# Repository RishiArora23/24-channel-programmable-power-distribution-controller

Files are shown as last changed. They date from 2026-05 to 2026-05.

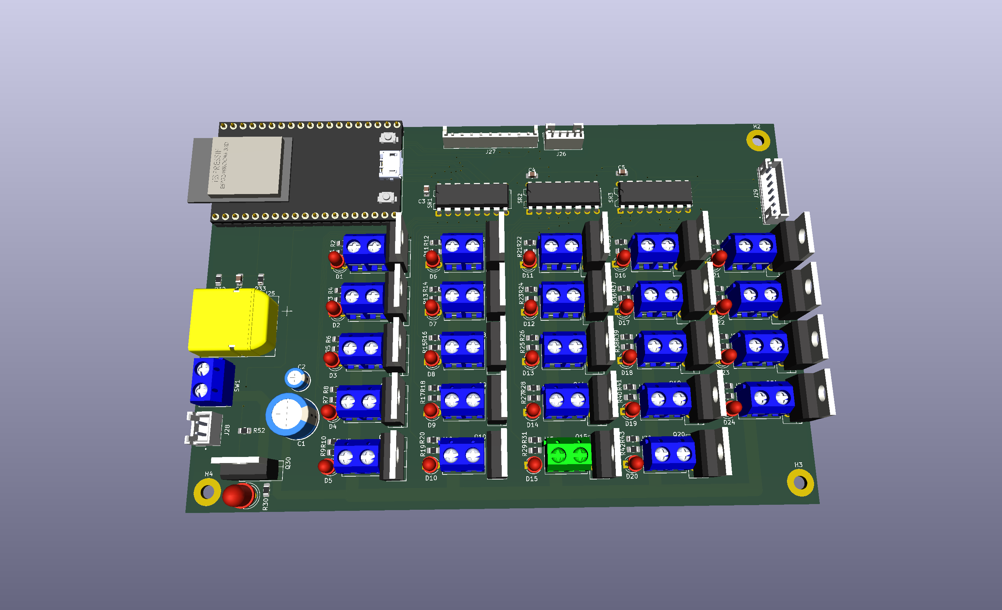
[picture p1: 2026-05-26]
images/pcb-layout_3d.png

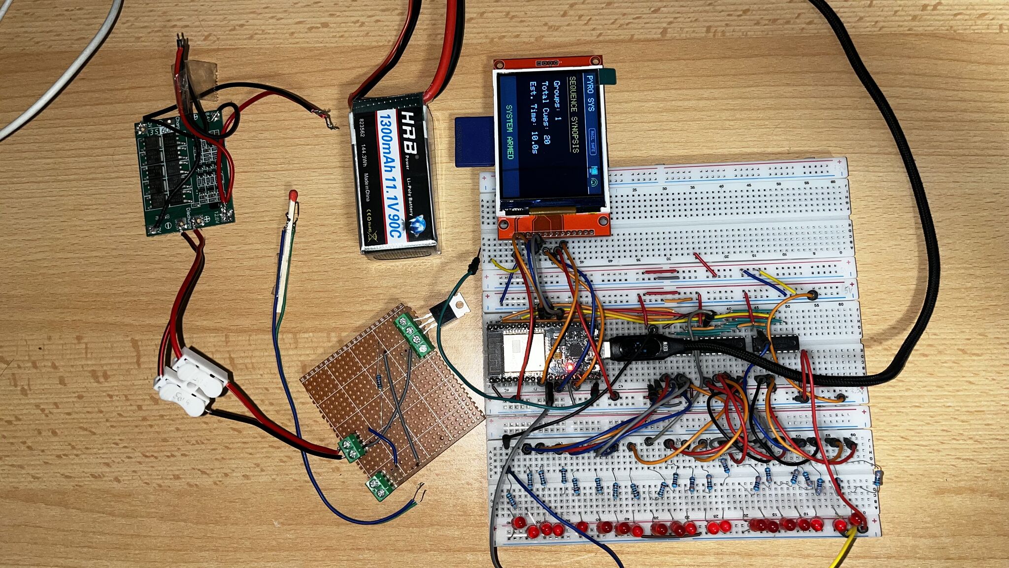
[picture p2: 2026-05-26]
images/prototype-photo.jpg

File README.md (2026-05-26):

# 24-Channel Programmable Power Distribution Controller

An ESP32-based programmable firing controller for sequenced 24-channel power distribution. The system combines embedded firmware, a KiCad-designed PCB, and a PyQt5 desktop application to enable fully programmable, remotely triggered output sequences — with hardware safety interlocks and a real-time TFT display.

> ⚠️ **Safety Notice:** This system switches high-current loads via power MOSFETs. Always follow applicable electrical safety guidelines. Never connect live loads during programming or testing.

---

## How It Works

Each of the 24 output channels is driven by an **IRLZ44N N-Channel MOSFET** (55 V, 47 A) switched via a **3× cascaded shift register** chain. The ESP32 clocks channel states into the shift registers over SPI, allowing all 24 outputs to be independently toggled in any order or pattern. A 12 V rail MOSFET acts as a master power switch, controlled by software arm/disarm commands.

The desktop app (`main.py`) communicates with the ESP32 over **Wi-Fi (TCP port 8080)** or via **UDP auto-discovery** (port 4210). Sequences are authored graphically in the app, serialized to JSON, and uploaded to the ESP32 at runtime — no re-flashing required.

---

## System Architecture

```
[ PyQt5 Desktop App ] ──WiFi TCP/UDP──► [ ESP32 Firmware ]
         │                                      │
   Sequence Editor                    Shift Registers (×3)
   Group/Pattern UI                         │
   Arm / Fire Controls              [ 24× IRLZ44N MOSFETs ]
                                            │
                                    [ Output Terminals J1–J24 ]
```

---

## Hardware

**Key components (from KiCad schematic):**
- **MCU:** ESP32 (Arduino framework)
- **Output switches:** 24× IRLZ44N MOSFETs in TO-220 package
- **Channel indicators:** 24× LEDs with 220 Ω series resistors
- **Gate drive:** 10 kΩ pull-down resistors per MOSFET gate
- **Shift registers:** 3× 8-bit shift registers (SRCLK → pin 23, RCLK → pin 21, SER → pin 22, OE → pin 19, SRCLR → pin 18)
- **Rail safety:** MOSFET switch on pin 27, analog voltage sense on pin 34
- **Display:** ILI9341 TFT (HSPI: MOSI 13, CLK 14, MISO 12, CS 5, DC 4, RST 17)
- **Output connectors:** 24× 2-pin 5.08 mm terminal blocks (J1–J24)

**Project files:**

| File | Description |
|---|---|
| `*.kicad_sch` | Schematic (channel sub-sheets × 24 + top sheet) |
| `*.kicad_pcb` | PCB layout |
| `*.kicad_pro` | KiCad project file |

---

## Firmware (`*.ino`)

Written in Arduino C++ for ESP32. Key responsibilities:

- **WiFiManager** captive portal for first-time Wi-Fi setup (AP: `Pyro-Setup-AP`)
- TCP server on port **8080** for desktop app communication
- UDP listener on port **4210** for auto-discovery
- Shift register management: channels fire for **1000 ms** then auto-clear
- JSON sequence parser (`ArduinoJson`) supporting up to **20 groups × 24 steps**
- Built-in web UI accessible from any browser on the network (manual fire, arm/disarm, sequence status)
- Real-time TFT UI with state machine: `IDLE → ARMED → COUNTDOWN → EXECUTING → FINISHED`

**ESP32 Pin Summary:**

| Function | Pin |
|---|-----|
| Rail MOSFET (arm) | 27 |
| Rail voltage sense | 34 |
| Shift reg SRCLK | 23 |
| Shift reg RCLK | 21 |
| Shift reg SER | 22 |
| Shift reg OE | 19 |
| Shift reg SRCLR | 18 |
| TFT MOSI/CLK/MISO/CS/DC/RST | 13/14/12/5/4/17 |

---

## Desktop App (`main.py`)

PyQt5 GUI application. Requires Python 3 and the following packages:

```bash
pip install PyQt5 pyserial
```

**Features:**
- Initialize a sequence with N cues (up to 24)
- Build named **groups** with patterns: Right Wave, Left Wave, Alternate, Center Burst, Inwards, All Fire
- Set inter-step gap (ms) per group
- Upload sequence as JSON to ESP32 over Wi-Fi
- Arm/disarm rail, monitor live rail voltage safety status
- Countdown display and per-channel LED flash feedback
- Undo/redo, save/load sequences as JSON files (`Ctrl+S` / `Ctrl+O`)
- **UDP Auto-Discovery** — finds the ESP32 on the local network automatically

**To run:**
```bash
python main.py
```

On first launch, connect the ESP32 to Wi-Fi via the `Pyro-Setup-AP` captive portal, then use **Auto Connect** in the app to discover it.

---

## Repository Structure

```
├── *.ino               # ESP32 Arduino firmware
├── main.py             # PyQt5 desktop control application
├── *.kicad_sch         # KiCad schematics (top + 24 channel sub-sheets)
├── *.kicad_pcb         # PCB layout
└── *.kicad_pro         # KiCad project
```

---

## License

This project is licensed under the [MIT License](LICENSE).

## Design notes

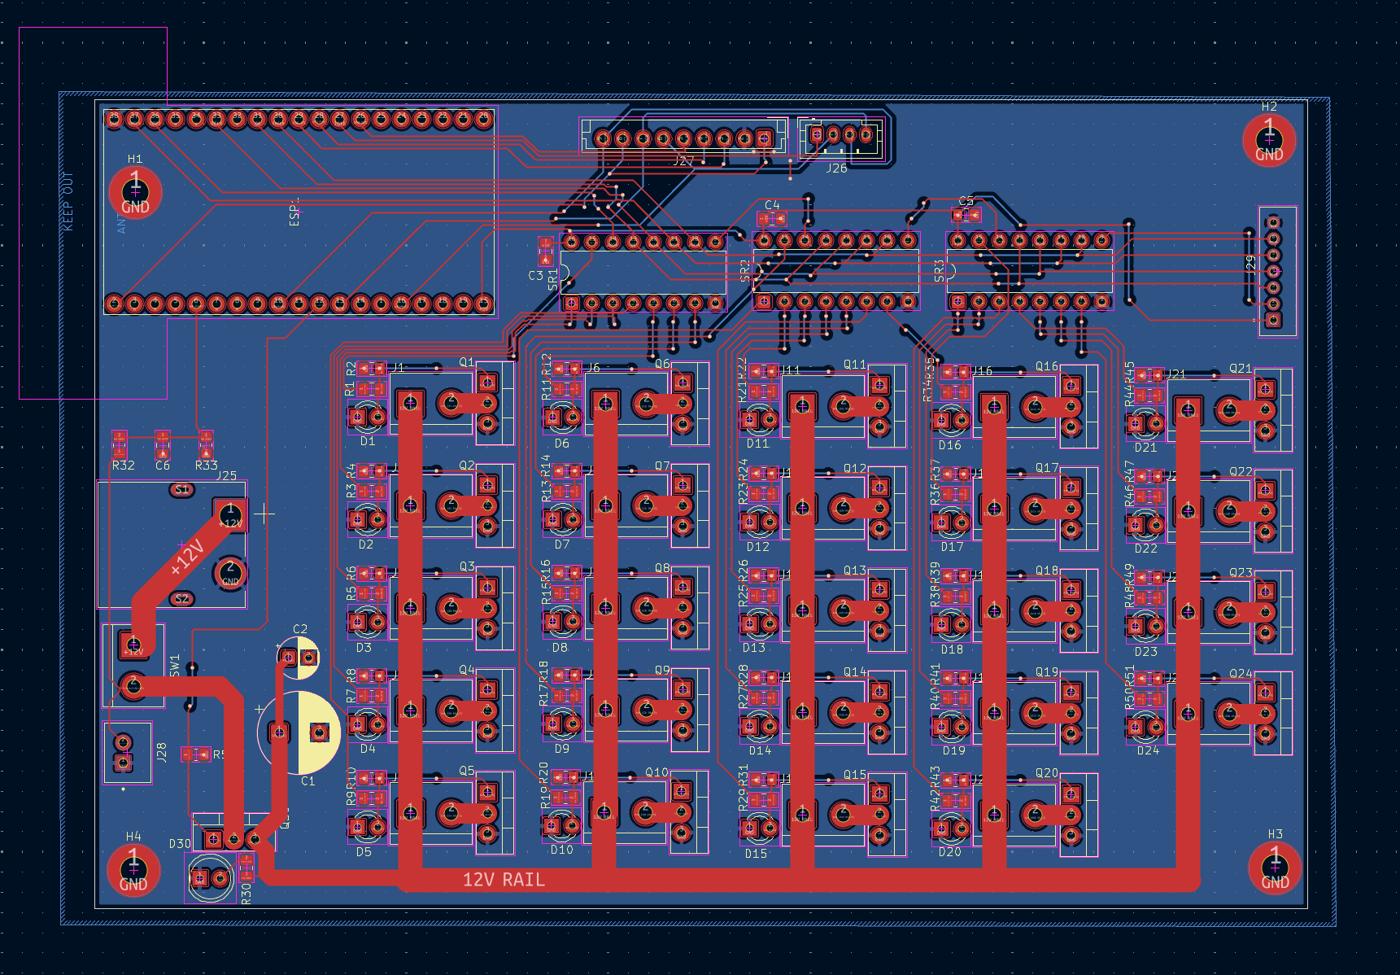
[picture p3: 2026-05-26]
images/pcb-layout.png

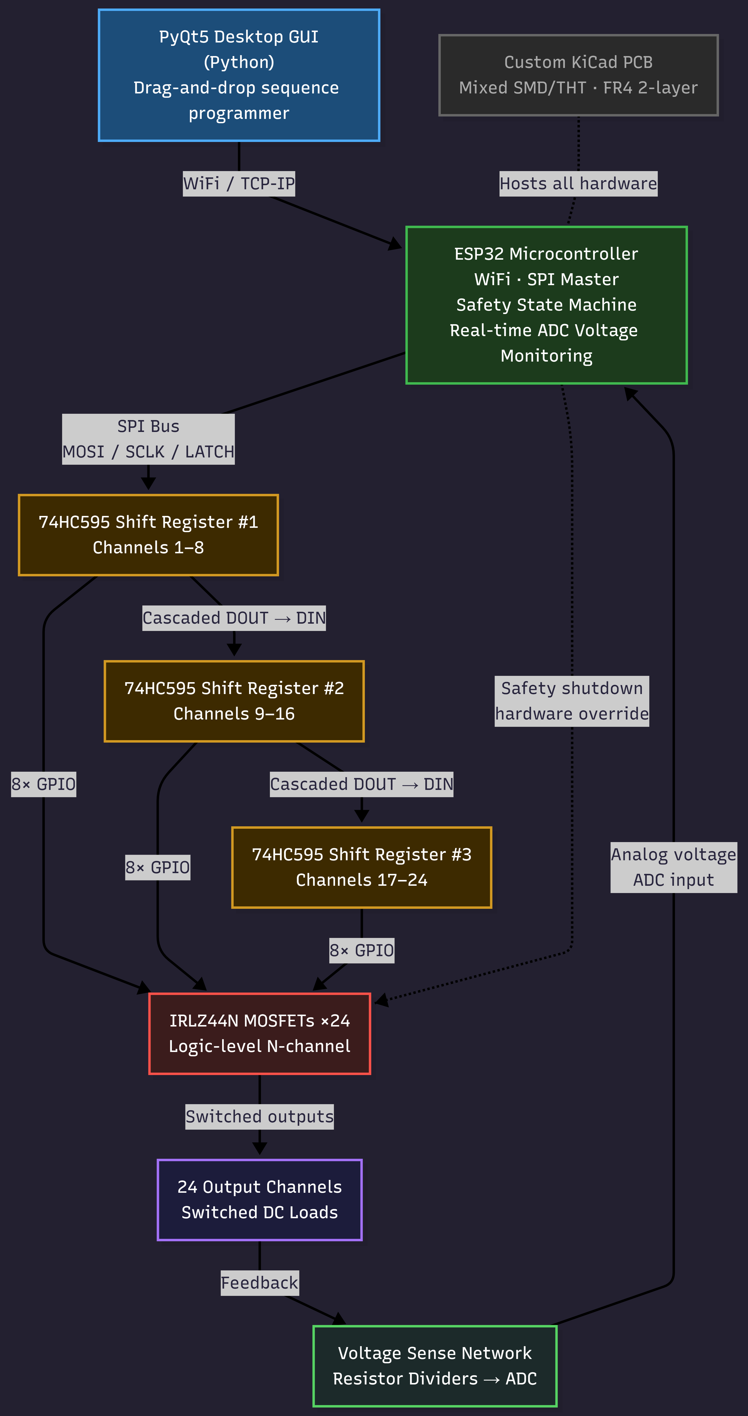
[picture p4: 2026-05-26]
images/block-diagram.png

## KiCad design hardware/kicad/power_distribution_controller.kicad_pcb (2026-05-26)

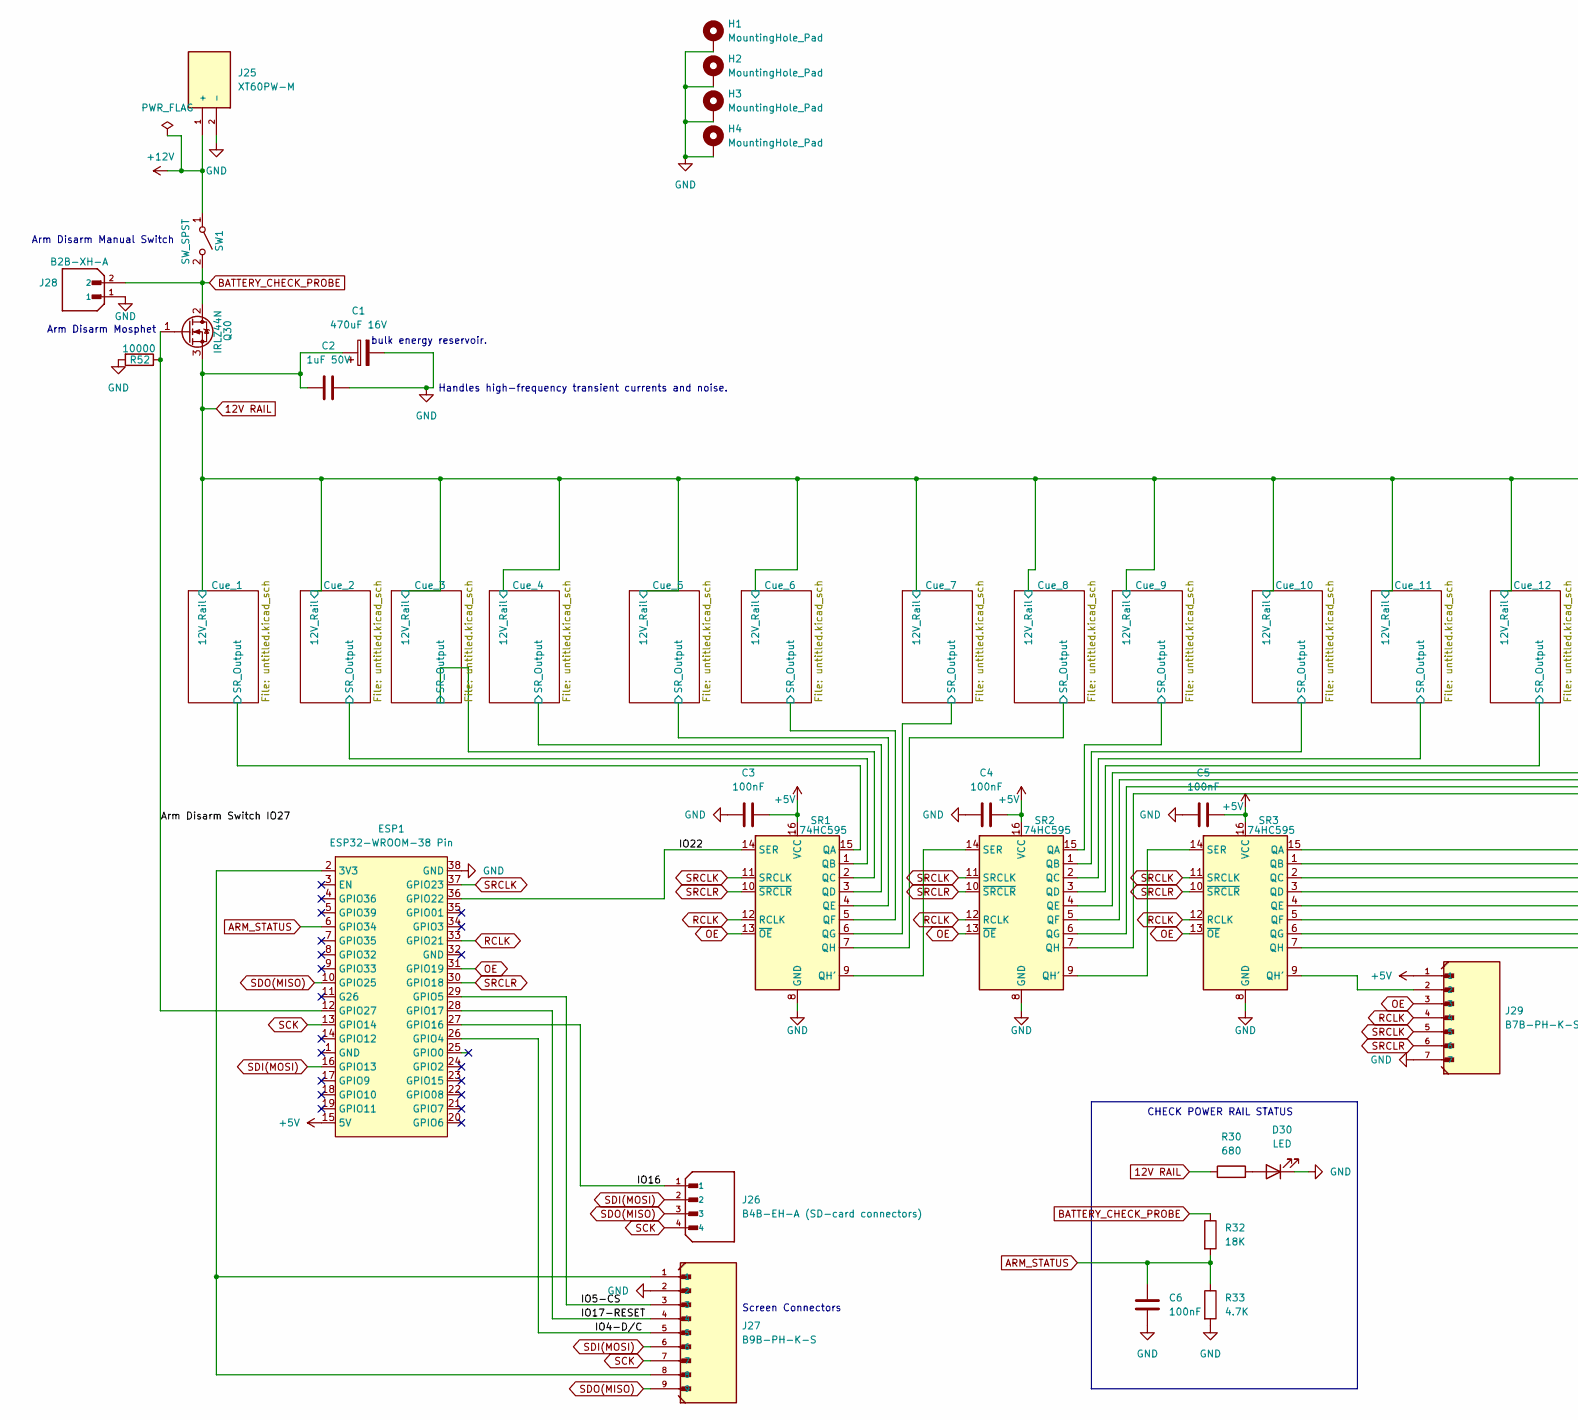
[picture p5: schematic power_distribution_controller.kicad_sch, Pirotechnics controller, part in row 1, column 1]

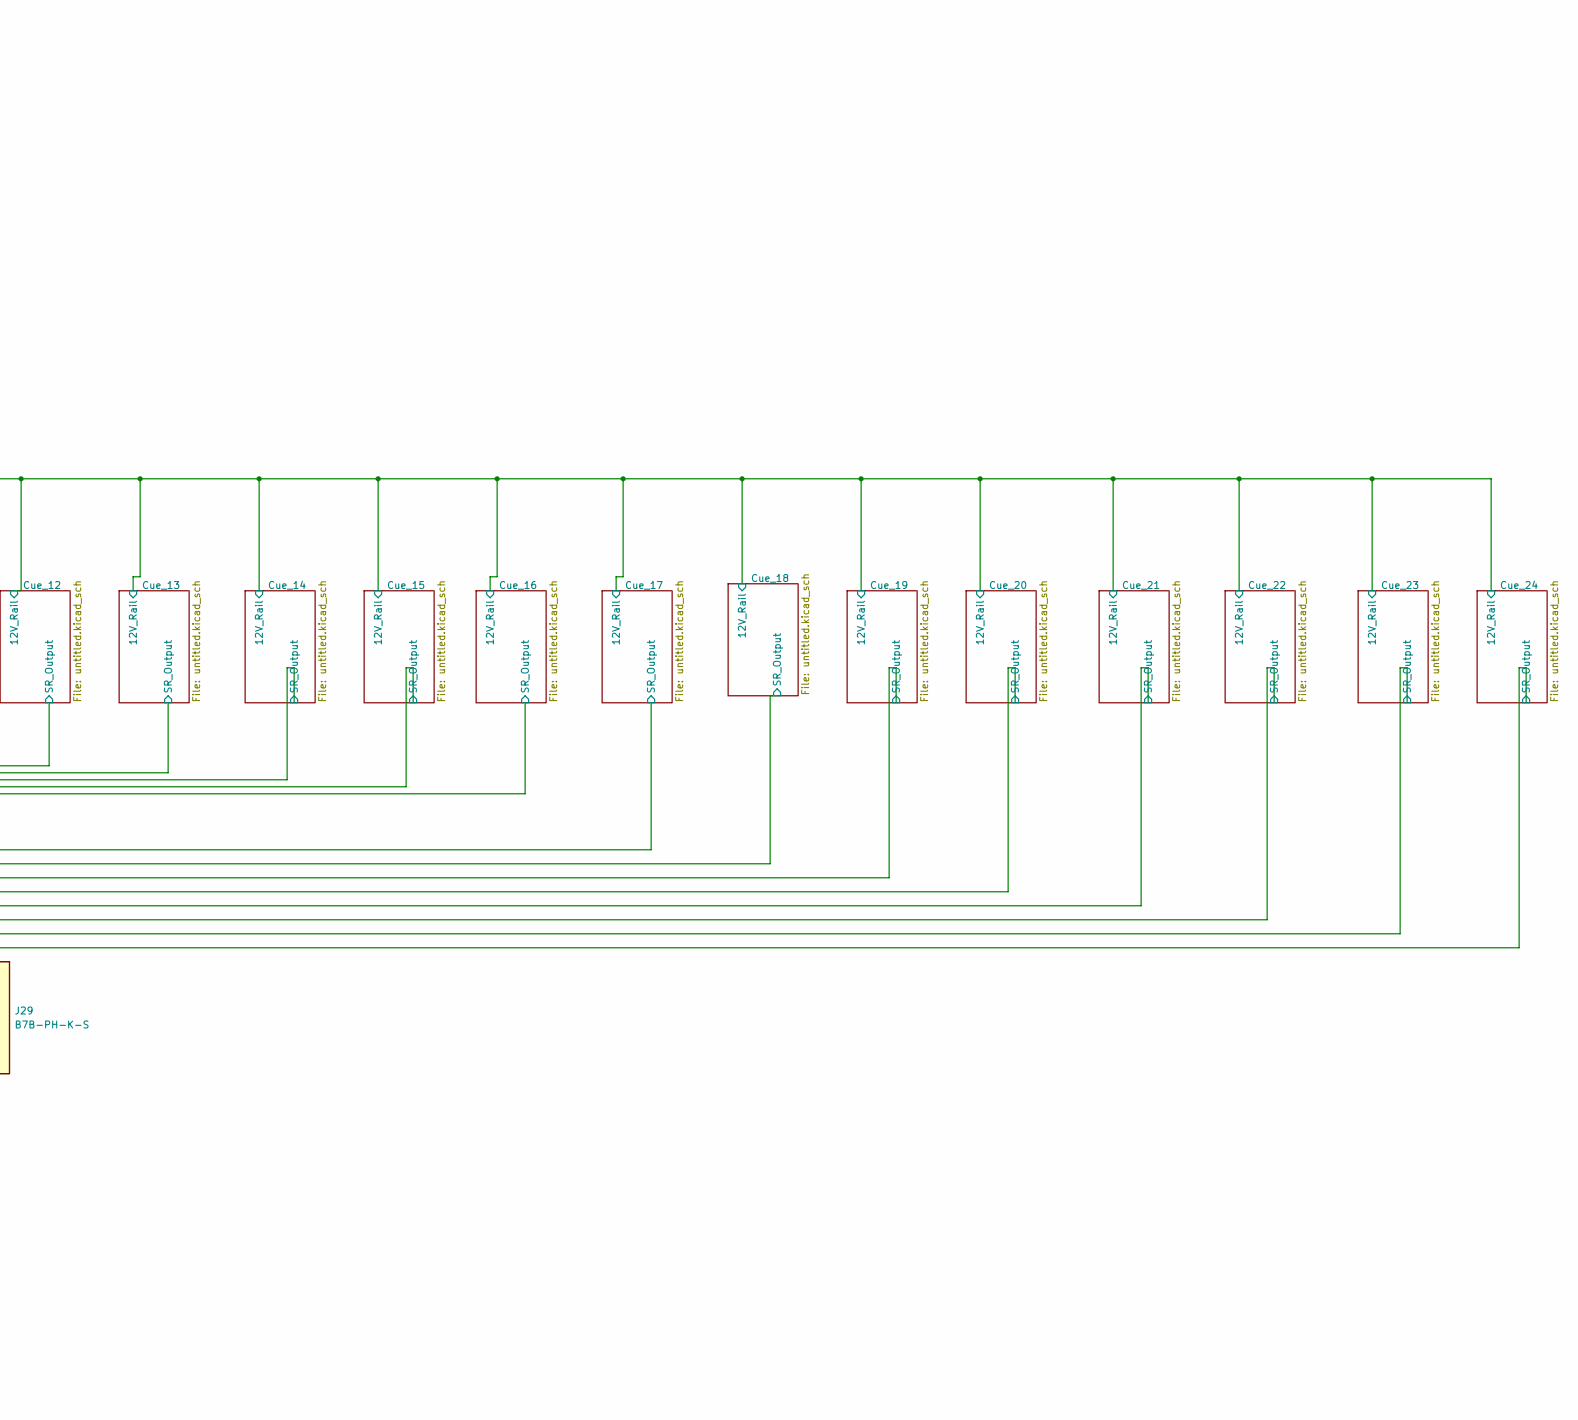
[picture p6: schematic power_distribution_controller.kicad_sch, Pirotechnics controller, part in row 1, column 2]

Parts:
C1: 470uF 16V; CP_Radial_D10.0mm_P5.00mm
C2: 1uF 50V; CP_Radial_D5.0mm_P2.50mm
C3, C4, C5, C6: 100nF; C_0805_2012Metric_Pad1.18x1.45mm_HandSolder
D30: LED; LED_D5.0mm
ESP1: ESP32-WROOM-38 Pin; ESP32_38Pin_THT
H1, H2, H3, H4: MountingHole_Pad; MountingHole_3.2mm_M3_Pad
J25: XT60PW-M; AMASS_XT60PW-M; PARTREV V1.2
J26: B4B-EH-A (SD-card connectors); JST_PH_B4B-PH-K_1x04_P2.00mm_Vertical
J27: B9B-PH-K-S; JST_EH_B9B-EH-A_1x09_P2.50mm_Vertical
J28: B2B-XH-A; JST_B2B-XH-A; PARTREV N/A
J29: B7B-PH-K-S; JST_B7B-PH-K-S
Q30: IRLZ44N; TO-220-3_Vertical
R30: 680; R_0805_2012Metric_Pad1.20x1.40mm_HandSolder
R32: 18K; R_0805_2012Metric_Pad1.20x1.40mm_HandSolder
R33: 4.7K; R_0805_2012Metric_Pad1.20x1.40mm_HandSolder
R52: 10000; R_0805_2012Metric_Pad1.20x1.40mm_HandSolder
SR1, SR2, SR3: 74HC595; DIP-16_W7.62mm
SW1: SW_SPST; TerminalBlock_bornier-2_P5.08mm

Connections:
12V RAIL: C1.1, C2.1, Q30.3 (S), R30.1; also elsewhere on the board
+5V: C3.1, C4.1, C5.1, ESP1.15 (5V), J29.1, SR1.16 (VCC), SR2.16 (VCC), SR3.16 (VCC)
+12V: J25.1 (+), SW1.1 (A)
/Arm Disarm Switch IO27: ESP1.12 (GPIO27), Q30.1 (G), R52.1
/Cue_1/SR_Output: SR1.15 (QA); also elsewhere on the board
/Cue_2/SR_Output: SR1.1 (QB); also elsewhere on the board
/Cue_3/SR_Output: SR1.2 (QC); also elsewhere on the board
/Cue_4/SR_Output: SR1.3 (QD); also elsewhere on the board
/Cue_5/SR_Output: SR1.4 (QE); also elsewhere on the board
/Cue_6/SR_Output: SR1.5 (QF); also elsewhere on the board
/Cue_7/SR_Output: SR1.6 (QG); also elsewhere on the board
/Cue_8/SR_Output: SR1.7 (QH); also elsewhere on the board
/Cue_9/SR_Output: SR2.15 (QA); also elsewhere on the board
/Cue_10/SR_Output: SR2.1 (QB); also elsewhere on the board
/Cue_11/SR_Output: SR2.2 (QC); also elsewhere on the board
/Cue_12/SR_Output: SR2.3 (QD); also elsewhere on the board
/Cue_13/SR_Output: SR2.4 (QE); also elsewhere on the board
/Cue_14/SR_Output: SR2.5 (QF); also elsewhere on the board
/Cue_15/SR_Output: SR2.6 (QG); also elsewhere on the board
/Cue_16/SR_Output: SR2.7 (QH); also elsewhere on the board
/Cue_17/SR_Output: SR3.15 (QA); also elsewhere on the board
/Cue_18/SR_Output: SR3.1 (QB); also elsewhere on the board
/Cue_19/SR_Output: SR3.2 (QC); also elsewhere on the board
/Cue_20/SR_Output: SR3.3 (QD); also elsewhere on the board
/Cue_21/SR_Output: SR3.4 (QE); also elsewhere on the board
/Cue_22/SR_Output: SR3.5 (QF); also elsewhere on the board
/Cue_23/SR_Output: SR3.6 (QG); also elsewhere on the board
/Cue_24/SR_Output: SR3.7 (QH); also elsewhere on the board
/IO4-D/C: ESP1.26 (GPIO4), J27.5
/IO5-CS: ESP1.29 (GPIO5), J27.3
/IO16: ESP1.27 (GPIO16), J26.1
/IO17-RESET: ESP1.28 (GPIO17), J27.4
/IO22: ESP1.36 (GPIO22), SR1.14 (SER)
ARM_STATUS: C6.1, ESP1.6 (GPIO34), R32.2, R33.1
BATTERY_CHECK_PROBE: J28.2, Q30.2 (D), R32.1, SW1.2 (B)
GND: C1.2, C2.2, C3.2, C4.2, C5.2, C6.2, D30.1 (K), ESP1.38 (GND), H1.1, H2.1, H3.1, H4.1, J25.2 (-), J27.2, J28.1, J29.7, R33.2, R52.2, SR1.8 (GND), SR2.8 (GND), SR3.8 (GND); also elsewhere on the board
unnamed: D30.2 (A), R30.2
unnamed: ESP1.2 (3V3), J27.1, J27.8
unnamed: SR1.9 (QH'), SR2.14 (SER)
unnamed: SR2.9 (QH'), SR3.14 (SER)
unnamed: J29.2, SR3.9 (QH')
OE: ESP1.31 (GPIO19), J29.3, SR1.13 (~OE), SR2.13 (~OE), SR3.13 (~OE)
RCLK: ESP1.33 (GPIO21), J29.4, SR1.12 (RCLK), SR2.12 (RCLK), SR3.12 (RCLK)
SCK: ESP1.13 (GPIO14), J26.4, J27.7
SDI(MOSI): ESP1.16 (GPIO13), J26.2, J27.6
SDO(MISO): ESP1.10 (GPIO25), J26.3, J27.9
SRCLK: ESP1.37 (GPIO23), J29.5, SR1.11 (SRCLK), SR2.11 (SRCLK), SR3.11 (SRCLK)
SRCLR: ESP1.30 (GPIO18), J29.6, SR1.10 (~SRCLR), SR2.10 (~SRCLR), SR3.10 (~SRCLR)

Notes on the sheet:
Arm Disarm Mosphet
CHECK POWER RAIL STATUS
Screen Connectors
Arm Disarm Manual Switch
bulk energy reservoir.
Handles high-frequency transient currents and noise.

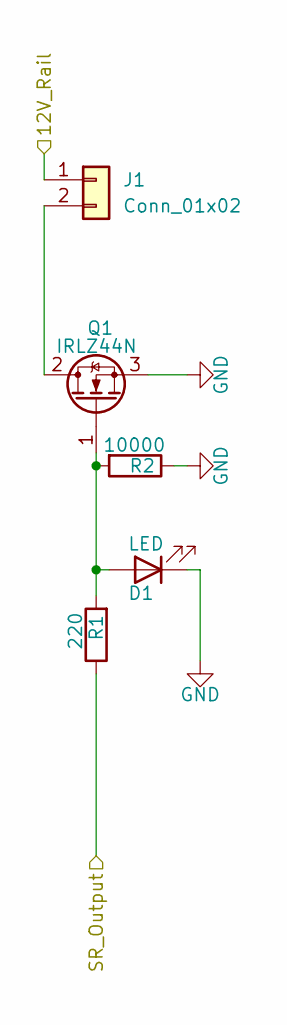
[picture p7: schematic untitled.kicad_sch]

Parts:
D1: LED; LED_D3.0mm
J1: Conn_01x02; TerminalBlock_bornier-2_P5.08mm
Q1: IRLZ44N; TO-220-3_Vertical
R1: 220; R_0805_2012Metric_Pad1.20x1.40mm_HandSolder
R2: 10000; R_0805_2012Metric_Pad1.20x1.40mm_HandSolder

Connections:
12V RAIL: J1.1; also elsewhere on the board
/Cue_1/SR_Output: R1.1; also elsewhere on the board
GND: D1.1 (K), Q1.3 (S), R2.1; also elsewhere on the board
unnamed: D1.2 (A), Q1.1 (G), R1.2, R2.2
unnamed: J1.2, Q1.2 (D)

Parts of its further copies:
D2, D3, D4, D5, D6, D7, D8, D9, D10, D11, D12, D13, D14, D15, D16, D17, D18, D19, D20, D21, D22, D23, D24: LED; LED_D3.0mm
J2, J3, J4, J5, J6, J7, J8, J9, J10, J11, J12, J13, J14, J15, J16, J17, J18, J19, J20, J21, J22, J23, J24: Conn_01x02; TerminalBlock_bornier-2_P5.08mm
Q2, Q3, Q4, Q5, Q6, Q7, Q8, Q9, Q10, Q11, Q12, Q13, Q14, Q15, Q16, Q17, Q18, Q19, Q20, Q21, Q22, Q23, Q24: IRLZ44N; TO-220-3_Vertical
R3, R5, R7, R9, R11, R13, R15, R17, R19, R21, R23, R25, R27, R29, R34, R36, R38, R40, R42, R44, R46, R48, R50: 220; R_0805_2012Metric_Pad1.20x1.40mm_HandSolder
R4, R6, R8, R10, R12, R14, R16, R18, R20, R22, R24, R26, R28, R31, R35, R37, R39, R41, R43, R45, R47, R49, R51: 10000; R_0805_2012Metric_Pad1.20x1.40mm_HandSolder

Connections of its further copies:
12V RAIL: J2.1, J3.1, J4.1, J5.1, J6.1, J7.1, J8.1, J9.1, J10.1, J11.1, J12.1, J13.1, J14.1, J15.1, J16.1, J17.1, J18.1, J19.1, J20.1, J21.1, J22.1, J23.1, J24.1; also elsewhere on the board
/Cue_2/SR_Output: R3.1; also elsewhere on the board
/Cue_3/SR_Output: R5.1; also elsewhere on the board
/Cue_4/SR_Output: R7.1; also elsewhere on the board
/Cue_5/SR_Output: R9.1; also elsewhere on the board
/Cue_6/SR_Output: R11.1; also elsewhere on the board
/Cue_7/SR_Output: R13.1; also elsewhere on the board
/Cue_8/SR_Output: R15.1; also elsewhere on the board
/Cue_9/SR_Output: R17.1; also elsewhere on the board
/Cue_10/SR_Output: R19.1; also elsewhere on the board
/Cue_11/SR_Output: R21.1; also elsewhere on the board
/Cue_12/SR_Output: R23.1; also elsewhere on the board
/Cue_13/SR_Output: R25.1; also elsewhere on the board
/Cue_14/SR_Output: R27.1; also elsewhere on the board
/Cue_15/SR_Output: R29.1; also elsewhere on the board
/Cue_16/SR_Output: R34.1; also elsewhere on the board
/Cue_17/SR_Output: R36.1; also elsewhere on the board
/Cue_18/SR_Output: R38.1; also elsewhere on the board
/Cue_19/SR_Output: R40.1; also elsewhere on the board
/Cue_20/SR_Output: R42.1; also elsewhere on the board
/Cue_21/SR_Output: R44.1; also elsewhere on the board
/Cue_22/SR_Output: R46.1; also elsewhere on the board
/Cue_23/SR_Output: R48.1; also elsewhere on the board
/Cue_24/SR_Output: R50.1; also elsewhere on the board
GND: D2.1 (K), D3.1 (K), D4.1 (K), D5.1 (K), D6.1 (K), D7.1 (K), D8.1 (K), D9.1 (K), D10.1 (K), D11.1 (K), D12.1 (K), D13.1 (K), D14.1 (K), D15.1 (K), D16.1 (K), D17.1 (K), D18.1 (K), D19.1 (K), D20.1 (K), D21.1 (K), D22.1 (K), D23.1 (K), D24.1 (K), Q2.3 (S), Q3.3 (S), Q4.3 (S), Q5.3 (S), Q6.3 (S), Q7.3 (S), Q8.3 (S), Q9.3 (S), Q10.3 (S), Q11.3 (S), Q12.3 (S), Q13.3 (S), Q14.3 (S), Q15.3 (S), Q16.3 (S), Q17.3 (S), Q18.3 (S), Q19.3 (S), Q20.3 (S), Q21.3 (S), Q22.3 (S), Q23.3 (S), Q24.3 (S), R4.1, R6.1, R8.1, R10.1, R12.1, R14.1, R16.1, R18.1, R20.1, R22.1, R24.1, R26.1, R28.1, R31.1, R35.1, R37.1, R39.1, R41.1, R43.1, R45.1, R47.1, R49.1, R51.1; also elsewhere on the board
unnamed: D2.2 (A), Q2.1 (G), R3.2, R4.2
unnamed: D3.2 (A), Q3.1 (G), R5.2, R6.2
unnamed: D4.2 (A), Q4.1 (G), R7.2, R8.2
unnamed: D5.2 (A), Q5.1 (G), R9.2, R10.2
unnamed: D6.2 (A), Q6.1 (G), R11.2, R12.2
unnamed: D7.2 (A), Q7.1 (G), R13.2, R14.2
unnamed: D8.2 (A), Q8.1 (G), R15.2, R16.2
unnamed: D9.2 (A), Q9.1 (G), R17.2, R18.2
unnamed: D10.2 (A), Q10.1 (G), R19.2, R20.2
unnamed: D11.2 (A), Q11.1 (G), R21.2, R22.2
unnamed: D12.2 (A), Q12.1 (G), R23.2, R24.2
unnamed: D13.2 (A), Q13.1 (G), R25.2, R26.2
unnamed: D14.2 (A), Q14.1 (G), R27.2, R28.2
unnamed: D15.2 (A), Q15.1 (G), R29.2, R31.2
unnamed: D16.2 (A), Q16.1 (G), R34.2, R35.2
unnamed: D17.2 (A), Q17.1 (G), R36.2, R37.2
unnamed: D18.2 (A), Q18.1 (G), R38.2, R39.2
unnamed: D19.2 (A), Q19.1 (G), R40.2, R41.2
unnamed: D20.2 (A), Q20.1 (G), R42.2, R43.2
unnamed: D21.2 (A), Q21.1 (G), R44.2, R45.2
unnamed: D22.2 (A), Q22.1 (G), R46.2, R47.2
unnamed: D23.2 (A), Q23.1 (G), R48.2, R49.2
unnamed: D24.2 (A), Q24.1 (G), R50.2, R51.2
unnamed: J2.2, Q2.2 (D)
unnamed: J3.2, Q3.2 (D)
unnamed: J4.2, Q4.2 (D)
unnamed: J5.2, Q5.2 (D)
unnamed: J6.2, Q6.2 (D)
unnamed: J7.2, Q7.2 (D)
unnamed: J8.2, Q8.2 (D)
unnamed: J9.2, Q9.2 (D)
unnamed: J10.2, Q10.2 (D)
unnamed: J11.2, Q11.2 (D)
unnamed: J12.2, Q12.2 (D)
unnamed: J13.2, Q13.2 (D)
unnamed: J14.2, Q14.2 (D)
unnamed: J15.2, Q15.2 (D)
unnamed: J16.2, Q16.2 (D)
unnamed: J17.2, Q17.2 (D)
unnamed: J18.2, Q18.2 (D)
unnamed: J19.2, Q19.2 (D)
unnamed: J20.2, Q20.2 (D)
unnamed: J21.2, Q21.2 (D)
unnamed: J22.2, Q22.2 (D)
unnamed: J23.2, Q23.2 (D)
unnamed: J24.2, Q24.2 (D)

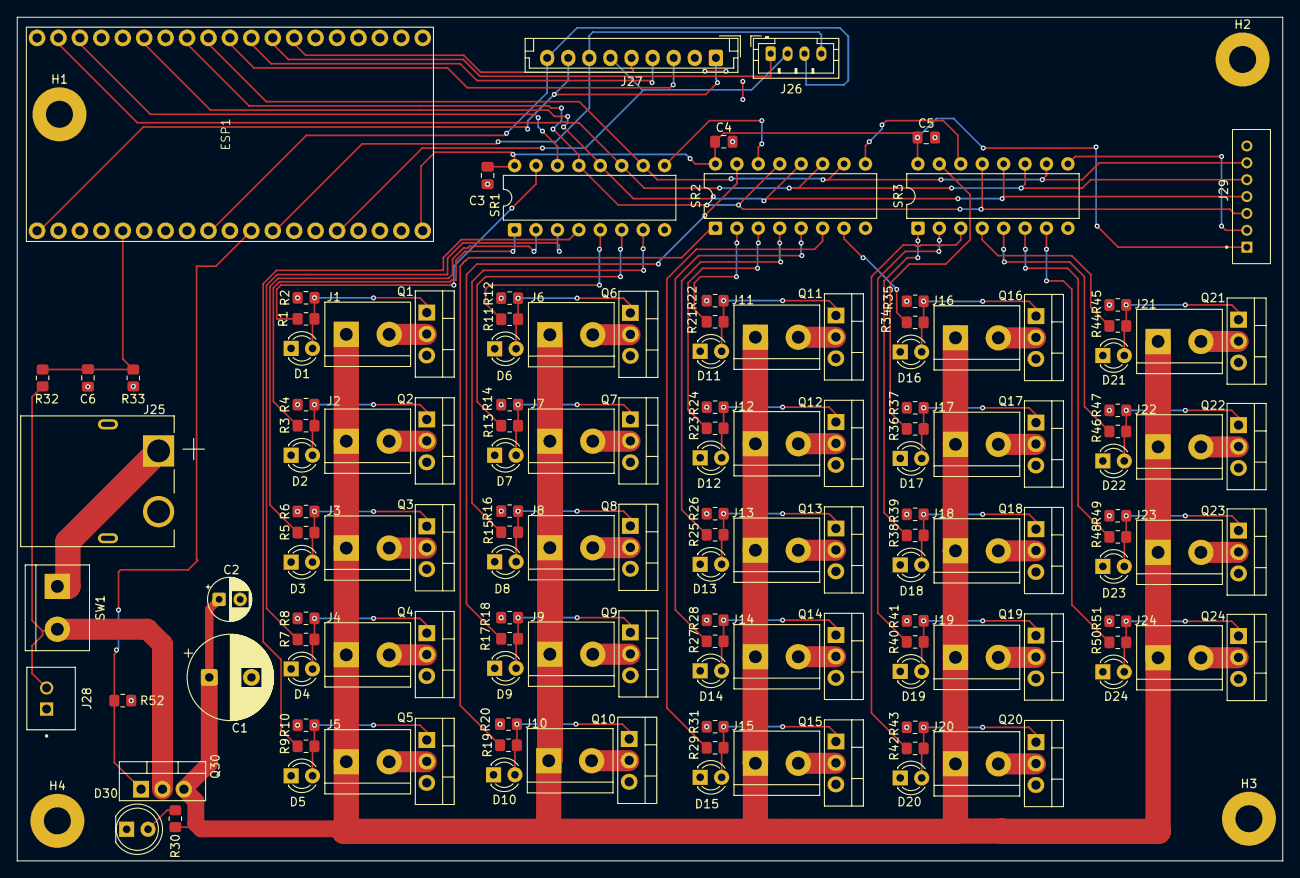
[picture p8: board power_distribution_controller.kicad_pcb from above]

Board: 2 copper layers, 150.0 x 100.0 mm, 146 parts (0 on the bottom side), 96 nets.

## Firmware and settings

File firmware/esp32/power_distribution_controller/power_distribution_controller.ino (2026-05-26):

// ==========================================================================
// SECTION 1: Includes and Initial Definitions
// ==========================================================================
#include <Arduino.h>
#include <SPI.h>
#include <Adafruit_GFX.h>
#include <Adafruit_ILI9341.h>
#include <ArduinoJson.h>
#include <climits>
#include <WiFi.h>
#include <WiFiUdp.h>       
#include <WebServer.h>     
#include <DNSServer.h>     
#include <WiFiManager.h>   

// ==========================================================================
// SECTION 2: Hardware Configuration & Constants
// ==========================================================================
WiFiServer server(8080); 
WiFiClient client;
WiFiUDP udp;
WebServer webServer(80); 

const unsigned int UDP_PORT = 4210; 
const char* DISCOVERY_PACKET = "PYRO_DISCOVERY_REQUEST";
const char* DISCOVERY_REPLY = "I_AM_PYRO_CONTROLLER";

// --- SAFETY & POWER PINS ---
#define PIN_RAIL_MOSFET  27  
#define PIN_RAIL_SENSE   34  

// --- TFT Pins (HSPI) ---
#define TFT_MOSI 13
#define TFT_CLK  14
#define TFT_MISO 12
#define TFT_CS   5
#define TFT_DC   4
#define TFT_RST  17

SPIClass hspi(HSPI);
Adafruit_ILI9341 tft = Adafruit_ILI9341(&hspi, TFT_DC, TFT_CS, TFT_RST);

// --- Shift Register Pins ---
#define SRCLK_PIN 23
#define RCLK_PIN 21
#define SER_PIN 22
#define OE_PIN 19
#define SRCLR_PIN 18

// --- System Limits ---
#define NUM_SHIFT_REGISTERS 3
#define CUES_PER_SR 8
#define TOTAL_CUES (NUM_SHIFT_REGISTERS * CUES_PER_SR)
#define MAX_GROUPS 20
#define MAX_STEPS_PER_GROUP TOTAL_CUES
#define SERIAL_BUFFER_SIZE 8192 
const unsigned long CUE_ON_DURATION_MS = 1000;
const int POST_SEQUENCE_TIMEOUT_SEC = 15; 

const char* JSON_SEQUENCE_START_CMD = "UPLOAD_JSON_START";
const char* JSON_SEQUENCE_END_CMD = "END_JSON_PAYLOAD";

// ==========================================================================
// SECTION 3: Data Structures
// ==========================================================================
struct FiringEventStep {
    int cuesToFire[TOTAL_CUES];
    byte numCuesInThisEvent;
};
struct Group {
    String name;
    String pattern;
    int gap_ms;
    FiringEventStep firingEvents[MAX_STEPS_PER_GROUP];
    byte numFiringEventsInGroup;
};
Group sequenceGroups[MAX_GROUPS];
byte totalGroupsInSequence = 0;

// ==========================================================================
// SECTION 4: State Machine & Variables
// ==========================================================================
enum SystemState { 
    IDLE, 
    WAITING_FOR_JSON, 
    ARMED, 
    COUNTDOWN, 
    EXECUTING_SEQUENCE, 
    SEQUENCE_FINISHED, 
    ERROR_STATE 
};
SystemState currentState = IDLE;

bool sequenceIsLoaded = false;
unsigned long nextStepTimestamp = 0;
unsigned long sequenceStartTime = 0;
unsigned long sequenceFinishedTime = 0; 
byte currentGroupIndex = 0;
byte currentStepIndex = 0;
int totalCuesFiredCount = 0;

// Stats
int statTotalCues = 0;
unsigned long statTotalDurationMs = 0;

// Safety Variables
bool isSoftwareArmed = false; 
bool isRailLive = false;      
unsigned long lastSafetyCheck = 0;

byte shiftRegisterStates[NUM_SHIFT_REGISTERS] = {0};
unsigned long cueClearTimestamps[TOTAL_CUES] = {0};

char serialInputBuffer[SERIAL_BUFFER_SIZE];
byte serialInputIndex = 0;
String jsonDataBuffer = "";

// Display Tracking
bool lastWifiState = false;
bool lastClientState = false;
int lastDrawnGroupIdx = -1;
int lastDrawnStepIdx = -1;
String lastCountdownStr = "";
bool lastRailLiveState = false;
int lastPostSeqTimerVal = -1;

// ==========================================================================
// SECTION 4.5: Web Interface HTML
// ==========================================================================
const char index_html[] PROGMEM = R"rawliteral(
<!DOCTYPE HTML><html><head>
  <meta name="viewport" content="width=device-width, initial-scale=1">
  <title>Pyro Remote</title>
  <style>
    body { background-color: #121212; color: white; font-family: sans-serif; text-align: center; margin:0; }
    .header { background-color: #1f1f1f; padding: 15px; font-size: 24px; font-weight: bold; border-bottom: 2px solid #333; }
    .tab-bar { display: flex; justify-content: space-around; background: #2c2c2c; padding: 10px 0; }
    .tab { flex: 1; padding: 10px; cursor: pointer; font-size: 18px; border-bottom: 3px solid transparent; }
    .tab.active { border-bottom: 3px solid #ff9800; color: #ff9800; }
    .content { display: none; padding: 20px; }
    .content.active { display: block; }
    
    .card { background: #333; border-radius: 10px; padding: 15px; margin: 15px 0; }
    .status-box { font-size: 20px; font-weight: bold; padding: 10px; border-radius: 5px; margin-top: 5px; }
    .safe { background-color: #4CAF50; color: white; }
    .danger { background-color: #F44336; color: white; }
    
    .btn { background: #555; color: white; border: none; padding: 15px 30px; font-size: 18px; border-radius: 5px; width: 80%; margin: 10px 0; cursor: pointer; }
    .btn-arm { background: #F44336; font-weight: bold; }
    .btn-disarm { background: #4CAF50; font-weight: bold; }
    .btn-start { background: #FF9800; font-weight: bold; color: black; }
    .btn-disabled { background: #444; color: #888; cursor: not-allowed; }
    
    .cue-grid { display: grid; grid-template-columns: repeat(4, 1fr); gap: 10px; margin-top: 15px; }
    .cue-btn { background: #444; border: 2px solid #666; color: white; padding: 15px; font-size: 16px; border-radius: 5px; }
    .cue-btn:active { background: #ff9800; border-color: #ff9800; }
  </style>
</head><body>
  <div class="header">Pyro System Remote</div>
  
  <div class="tab-bar">
    <div class="tab active" onclick="showTab('dashboard')">Dashboard</div>
    <div class="tab" onclick="showTab('manual')">Manual Fire</div>
  </div>

  <div id="dashboard" class="content active">
    <div class="card">
      <div>System Arm State</div>
      <div id="armState" class="status-box safe">DISARMED</div>
    </div>
    <div class="card">
      <div>Rail Voltage (Safety)</div>
      <div id="railState" class="status-box safe">SAFE</div>
    </div>
    
    <button id="toggleArmBtn" class="btn btn-arm" onclick="toggleArm()">ARM SYSTEM</button>
    
    <div class="card">
      <div>Sequence Status</div>
      <div id="seqStatus" style="font-size: 18px; color: #ccc; margin-top:5px;">IDLE</div>
      <div id="uploadStatus" style="font-size: 14px; color: #888; margin-top:5px;">No Sequence Loaded</div>
    </div>
    
    <!-- NEW START BUTTON -->
    <button id="startSeqBtn" class="btn btn-disabled" onclick="startSequence()" disabled>START SEQUENCE</button>
  </div>

  <div id="manual" class="content">
    <div style="color: #FF9800; font-size: 14px;">Tap to Fire Immediately (500ms Pulse)</div>
    <div class="cue-grid" id="cueGrid"></div>
  </div>

<script>
  const grid = document.getElementById('cueGrid');
  for(let i=1; i<=24; i++) {
    let b = document.createElement('button');
    b.className = 'cue-btn';
    b.innerText = i;
    b.onclick = () => fireCue(i);
    grid.appendChild(b);
  }

  function showTab(id) {
    document.querySelectorAll('.content').forEach(c => c.classList.remove('active'));
    document.querySelectorAll('.tab').forEach(t => t.classList.remove('active'));
    document.getElementById(id).classList.add('active');
    event.target.classList.add('active');
  }

  function updateStatus() {
    fetch('/api/status').then(r => r.json()).then(d => {
      const armEl = document.getElementById('armState');
      const armBtn = document.getElementById('toggleArmBtn');
      const startBtn = document.getElementById('startSeqBtn');
      const uploadEl = document.getElementById('uploadStatus');
      
      if(d.armed) {
        armEl.innerText = "ARMED";
        armEl.className = "status-box danger";
        armBtn.innerText = "DISARM SYSTEM";
        armBtn.className = "btn btn-disarm";
      } else {
        armEl.innerText = "DISARMED";
        armEl.className = "status-box safe";
        armBtn.innerText = "ARM SYSTEM";
        armBtn.className = "btn btn-arm";
      }

      const railEl = document.getElementById('railState');
      if(d.railLive) {
        railEl.innerText = "LIVE (DANGER)";
        railEl.className = "status-box danger";
      } else {
        railEl.innerText = "SAFE";
        railEl.className = "status-box safe";
      }
      
      document.getElementById('seqStatus').innerText = d.stateStr; // Use text version
      
      if(d.hasSeq) {
        uploadEl.innerText = "Sequence Loaded";
        uploadEl.style.color = "#4CAF50";
        
        // FIXED LOGIC: Enable Start Button if Loaded, regardless of Arm state (for Test Mode)
        // Only disable if already executing
        if(d.stateStr !== "EXECUTING") {
            startBtn.disabled = false;
            startBtn.className = "btn btn-start";
        } else {
            startBtn.disabled = true;
            startBtn.className = "btn btn-disabled";
        }
      } else {
        uploadEl.innerText = "No Sequence Loaded";
        uploadEl.style.color = "#888";
        startBtn.disabled = true;
        startBtn.className = "btn btn-disabled";
      }
    });
  }

  function toggleArm() { fetch('/api/toggleArm').then(() => setTimeout(updateStatus, 200)); }
  function fireCue(num) { fetch('/api/fire?cue=' + num); }
  function startSequence() { fetch('/api/startSeq'); } 

  setInterval(updateStatus, 1000);
  updateStatus();
</script>
</body></html>
)rawliteral";


// ==========================================================================
// SECTION 5: Function Prototypes
// ==========================================================================
void setupHardware();
void checkRailSafety();
void handleUdpDiscovery(); 
void handleWebServer(); 
void drawHeaderIcons(bool forceRedraw);
void drawSequenceSummary(); 
void drawTimelineList(int activeGroupIdx, int activeStepIdx);
void drawFullScreenCountdown(String numStr);
void drawSequenceCompleteScreen(int secondsLeft);
void handleCommunication();
void processCommand(const String& cmd);
bool parseSequenceFromJson(const String& jsonString);
void executeNow();
void executeSequenceStep();
void fireCue(int cueNumber);
void checkAndClearCues();
void updateShiftRegisters();
void clearAllOutputs();
void resetSequenceState();
void enterErrorState(const String& reason);
String getEventDescription(int gIdx, int sIdx);
String getStateString(); // New Helper

// ==========================================================================
// SECTION 6: Setup Function
// ==========================================================================
void setup() {
    Serial.begin(115200);
    Serial.println("\n\n--- Pyro Control ESP32 (V17 Web Start Fixed) ---");

    setupHardware();
    
    hspi.begin(TFT_CLK, TFT_MISO, TFT_MOSI, TFT_CS); 
    tft.begin();
    tft.setRotation(1);
    tft.fillScreen(ILI9341_BLACK);
    
    tft.setTextColor(ILI9341_ORANGE);
    tft.setTextSize(2);
    tft.setCursor(50, 80);
    tft.print("PYRO SYSTEM BOOT");
    tft.setCursor(50, 110);
    tft.setTextSize(1);
    tft.print("Connecting to WiFi...");

    WiFiManager wifiManager;
    bool res = wifiManager.autoConnect("Pyro-Setup-AP", "password"); 
    
    if(!res) {
        tft.setTextColor(ILI9341_RED);
        tft.setCursor(50, 130);
        tft.print("Failed to connect. Restarting...");
        delay(3000);
        ESP.restart();
    } 
    
    udp.begin(UDP_PORT);
    server.begin();
    
    // --- Setup Web Server Routes ---
    webServer.on("/", HTTP_GET, []() {
        webServer.send(200, "text/html", index_html);
    });
    
    webServer.on("/api/status", HTTP_GET, []() {
        String json = "{";
        json += "\"armed\":" + String(isSoftwareArmed ? "true" : "false") + ",";
        json += "\"railLive\":" + String(isRailLive ? "true" : "false") + ",";
        json += "\"stateStr\":\"" + getStateString() + "\","; // Human readable
        json += "\"hasSeq\":" + String(sequenceIsLoaded ? "true" : "false");
        json += "}";
        webServer.send(200, "application/json", json);
    });

    webServer.on("/api/toggleArm", HTTP_GET, []() {
        if (isSoftwareArmed) {
            digitalWrite(PIN_RAIL_MOSFET, LOW);
            isSoftwareArmed = false;
        } else {
            digitalWrite(PIN_RAIL_MOSFET, HIGH);
            isSoftwareArmed = true;
        }
        if(client.connected()) client.println(isSoftwareArmed ? "ACK ARM" : "ACK DISARM");
        webServer.send(200, "text/plain", "OK");
    });

    webServer.on("/api/fire", HTTP_GET, []() {
        if (webServer.hasArg("cue")) {
            int cue = webServer.arg("cue").toInt();
            if (currentState != EXECUTING_SEQUENCE) {
                fireCue(cue);
                updateShiftRegisters();
                webServer.send(200, "text/plain", "FIRED");
            } else {
                webServer.send(403, "text/plain", "BUSY");
            }
        } else {
            webServer.send(400, "text/plain", "Missing cue param");
        }
    });
    
    // NEW ENDPOINT: Start Sequence
    webServer.on("/api/startSeq", HTTP_GET, []() {
        // FIXED LOGIC: Allow start if sequence loaded, even if not armed (Test Mode)
        if (sequenceIsLoaded && currentState != EXECUTING_SEQUENCE) {
            executeNow();
            webServer.send(200, "text/plain", "STARTED");
        } else {
            webServer.send(400, "text/plain", "CANNOT START");
        }
    });
    
    webServer.begin();
    // -------------------------------
    
    delay(500);
    
    tft.fillScreen(ILI9341_BLACK);
    drawHeaderIcons(true); 
    
    tft.setTextColor(ILI9341_GREEN);
    tft.setTextSize(2);
    tft.setCursor(10, 50);
    tft.print("IP: ");
    tft.println(WiFi.localIP());
    
    resetSequenceState(); 
}

// ==========================================================================
// SECTION 7: Main Loop
// ==========================================================================
void loop() {
    webServer.handleClient(); 
    handleCommunication();
    handleUdpDiscovery(); 
    checkAndClearCues();
    checkRailSafety(); 
    
    static unsigned long lastIconUpdate = 0;
    if (millis() - lastIconUpdate > 1000) {
        drawHeaderIcons(false);
        lastIconUpdate = millis();
    }

    if (currentState == EXECUTING_SEQUENCE) {
        executeSequenceStep();
    } else if (currentState == SEQUENCE_FINISHED) {
        unsigned long elapsed = (millis() - sequenceFinishedTime) / 1000;
        int remaining = POST_SEQUENCE_TIMEOUT_SEC - elapsed;
        if (remaining < 0) resetSequenceState(); 
        else drawSequenceCompleteScreen(remaining);
    }
}

// ==========================================================================
// SECTION 8: Hardware & UDP Init
// ==========================================================================
void setupHardware() {
    pinMode(SRCLK_PIN, OUTPUT);
    pinMode(RCLK_PIN, OUTPUT);
    pinMode(SER_PIN, OUTPUT);
    pinMode(OE_PIN, OUTPUT);
    pinMode(SRCLR_PIN, OUTPUT);
    
    pinMode(PIN_RAIL_MOSFET, OUTPUT);
    digitalWrite(PIN_RAIL_MOSFET, LOW); 
    pinMode(PIN_RAIL_SENSE, INPUT); 

    digitalWrite(SRCLR_PIN, HIGH);
    digitalWrite(OE_PIN, LOW);
    digitalWrite(RCLK_PIN, LOW);
    digitalWrite(SRCLK_PIN, LOW);
    digitalWrite(SER_PIN, LOW);

    clearAllOutputs();
}

void handleUdpDiscovery() {
    int packetSize = udp.parsePacket();
    if (packetSize) {
        char packetBuffer[255];
        int len = udp.read(packetBuffer, 255);
        if (len > 0) packetBuffer[len] = 0;

        if (strcmp(packetBuffer, DISCOVERY_PACKET) == 0) {
            udp.beginPacket(udp.remoteIP(), udp.remotePort());
            udp.print(DISCOVERY_REPLY);
            udp.endPacket();
        }
    }
}

void clearAllOutputs() {
    byte cleanState[NUM_SHIFT_REGISTERS] = {0}; 
    digitalWrite(OE_PIN, HIGH);
    digitalWrite(RCLK_PIN, LOW);
    shiftOut(SER_PIN, SRCLK_PIN, MSBFIRST, cleanState[2]);
    shiftOut(SER_PIN, SRCLK_PIN, MSBFIRST, cleanState[1]);
    shiftOut(SER_PIN, SRCLK_PIN, MSBFIRST, cleanState[0]);
    digitalWrite(RCLK_PIN, HIGH);
    digitalWrite(OE_PIN, LOW);

    memset(shiftRegisterStates, 0, sizeof(shiftRegisterStates));
    memset(cueClearTimestamps, 0, sizeof(cueClearTimestamps));
}

void updateShiftRegisters() {
    digitalWrite(OE_PIN, HIGH);
    digitalWrite(RCLK_PIN, LOW);
    shiftOut(SER_PIN, SRCLK_PIN, MSBFIRST, shiftRegisterStates[2]);
    shiftOut(SER_PIN, SRCLK_PIN, MSBFIRST, shiftRegisterStates[1]);
    shiftOut(SER_PIN, SRCLK_PIN, MSBFIRST, shiftRegisterStates[0]);
    digitalWrite(RCLK_PIN, HIGH);
    digitalWrite(OE_PIN, LOW);
}

// ==========================================================================
// SECTION 9: TFT UI & Safety Logic
// ==========================================================================
String getStateString() {
    switch(currentState) {
        case IDLE: return "IDLE";
        case WAITING_FOR_JSON: return "WAITING...";
        case ARMED: return "ARMED / READY";
        case COUNTDOWN: return "COUNTDOWN";
        case EXECUTING_SEQUENCE: return "EXECUTING";
        case SEQUENCE_FINISHED: return "FINISHED";
        case ERROR_STATE: return "ERROR";
        default: return "UNKNOWN";
    }
}

void checkRailSafety() {
    if (millis() - lastSafetyCheck < 200) return; 
    lastSafetyCheck = millis();

    int val = analogRead(PIN_RAIL_SENSE);
    bool liveNow = (val > 500);
    
    if (liveNow != isRailLive) {
        isRailLive = liveNow;
        if (client.connected()) {
            client.print("RAIL:");
            client.println(isRailLive ? "LIVE" : "SAFE");
        }
        drawHeaderIcons(true);
    }
}

void drawHeaderIcons(bool forceRedraw) {
    if (currentState == COUNTDOWN) return;

    bool wifiNow = (WiFi.status() == WL_CONNECTED);
    bool clientNow = client.connected();
    
    if (!forceRedraw && wifiNow == lastWifiState && clientNow == lastClientState && isRailLive == lastRailLiveState) return;

    int headerH = 30;
    if (forceRedraw) {
        tft.fillRect(0, 0, 320, headerH, 0x2124); 
        tft.drawFastHLine(0, headerH, 320, ILI9341_WHITE);
        tft.setTextColor(ILI9341_WHITE);
        tft.setTextSize(2);
        tft.setCursor(10, 7);
        tft.print("PYRO SYS");
    }
    
    int rX = 150; int rY = 7;
    if (isRailLive) {
        tft.fillRoundRect(rX, rY, 70, 16, 4, ILI9341_RED);
        tft.setTextColor(ILI9341_WHITE);
        tft.setTextSize(1);
        tft.setCursor(rX + 8, rY + 4);
        tft.print("RAIL LIVE");
    } else {
        tft.drawRoundRect(rX, rY, 70, 16, 4, 0x7BEF); 
        tft.setTextColor(0x7BEF);
        tft.setTextSize(1);
        tft.setCursor(rX + 8, rY + 4);
        tft.print("RAIL SAFE");
    }

    int wX = 290; int wY = 22;
    uint16_t wColor = wifiNow ? ILI9341_GREEN : ILI9341_RED;
    tft.fillRect(wX-10, 0, 30, headerH, 0x2124); 
    tft.fillCircle(wX, wY, 2, wColor);
    tft.drawCircle(wX, wY-4, 6, wColor);
    tft.drawCircle(wX, wY-4, 10, wColor);
    tft.fillRect(wX-12, wY+1, 24, 10, 0x2124); 

    int pX = 250; int pY = 15;
    uint16_t pColor = clientNow ? ILI9341_CYAN : ILI9341_RED;
    tft.drawRect(pX, pY-8, 20, 14, pColor);
    tft.fillRect(pX+2, pY-6, 16, 10, pColor); 
    tft.drawFastHLine(pX+6, pY+8, 8, pColor);
    tft.drawFastHLine(pX+4, pY+9, 12, pColor);

    lastWifiState = wifiNow;
    lastClientState = clientNow;
    lastRailLiveState = isRailLive;
}

void drawFullScreenCountdown(String numStr) {
    if (lastCountdownStr == "") tft.fillScreen(ILI9341_BLACK);
    if (numStr == lastCountdownStr) return;
    
    tft.fillScreen(ILI9341_BLACK); 
    tft.setTextColor(ILI9341_YELLOW);
    tft.setTextSize(14); 
    
    int16_t x1, y1; uint16_t w, h;
    tft.getTextBounds(numStr, 0, 0, &x1, &y1, &w, &h);
    int x = (320 - w) / 2;
    int y = (240 - h) / 2 + h/2 - 20;
    
    tft.setCursor(x, y);
    tft.print(numStr);
    
    tft.setTextSize(2);
    if (isRailLive) {
        tft.setTextColor(ILI9341_RED);
        tft.setCursor(60, 210);
        tft.print("DANGER: RAIL LIVE");
    } else {
        tft.setTextColor(ILI9341_GREEN);
        tft.setCursor(70, 210);
        tft.print("TEST MODE (SAFE)");
    }
    
    lastCountdownStr = numStr;
}

void drawSequenceSummary() {
    tft.fillScreen(ILI9341_BLACK);
    drawHeaderIcons(true);

    tft.setTextColor(ILI9341_ORANGE);
    tft.setTextSize(2);
    tft.setCursor(10, 50);
    tft.print("SEQUENCE SYNOPSIS");
    tft.drawFastHLine(10, 70, 200, ILI9341_ORANGE);

    tft.setTextColor(ILI9341_WHITE);
    tft.setTextSize(2);
    tft.setCursor(20, 90); tft.print("Groups: "); tft.print(totalGroupsInSequence);
    tft.setCursor(20, 120); tft.print("Total Cues: "); tft.print(statTotalCues);
    tft.setCursor(20, 150); tft.print("Est. Time: "); tft.print(statTotalDurationMs / 1000.0, 1); tft.print("s");

    tft.fillRect(0, 200, 320, 40, 0x2124); 
    tft.setTextColor(ILI9341_GREEN);
    tft.setCursor(80, 212);
    tft.print("SYSTEM ARMED");
}

String getEventDescription(int gIdx, int sIdx) {
    if (gIdx >= totalGroupsInSequence) return "";
    Group& g = sequenceGroups[gIdx];
    String desc = g.name.substring(0, 9) + ": ";
    if (g.pattern == "Pause") desc += "Pause " + String(g.gap_ms) + "ms";
    else {
        if (sIdx < g.numFiringEventsInGroup) {
            FiringEventStep& step = g.firingEvents[sIdx];
            desc += "Fire ";
            for(int i=0; i<step.numCuesInThisEvent; i++) {
                desc += String(step.cuesToFire[i]);
                if (i < step.numCuesInThisEvent - 1) desc += ",";
            }
        }
    }
    return desc;
}
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

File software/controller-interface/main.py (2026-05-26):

# START SECTION 1: Imports and Constants
import sys
import hashlib  # Add to imports
from functools import partial
from PyQt5.QtWidgets import (
    QApplication, QMainWindow, QVBoxLayout, QHBoxLayout, QWidget,
    QPushButton, QLineEdit, QLabel, QListWidget, QListWidgetItem,
    QInputDialog, QMessageBox, QMenu, QGridLayout, QDialog,
    QDialogButtonBox, QScrollArea, QCheckBox, QSpinBox, QColorDialog,
    QComboBox, QSizePolicy, QProgressDialog, QAction, QFileDialog
)
from PyQt5.QtCore import Qt, QTimer, QPoint, QSize, QThread, pyqtSignal
from PyQt5.QtGui import QColor, QCursor

import json # Already present, will be used more
import serial
import time
import socket

UDP_DISCOVERY_PORT = 4210
DISCOVERY_PACKET = b"PYRO_DISCOVERY_REQUEST" # Note the 'b' for bytes
DISCOVERY_REPLY = "I_AM_PYRO_CONTROLLER"

ESP32_IP = "192.168.0.156"  # <<< CHANGE THIS TO THE IP FROM ARDUINO SERIAL MONITOR
ENABLE_WIFI = True # Use this as our main flag now

# New constants for JSON communication
JSON_SEQUENCE_START_CMD = "UPLOAD_JSON_START"
JSON_SEQUENCE_END_CMD = "END_JSON_PAYLOAD" # To mark the end of a potentially large JSON string
# END SECTION 1: Imports and Constants
# START SECTION 2: SerialWorker Class
class SerialWorker(QThread):
    """
    Handles serial communication in a separate thread to prevent blocking the GUI.
    """
    # Signals emitted by the worker thread
    data_received = pyqtSignal(str)      # Emits incoming data lines from ESP32
    connection_status = pyqtSignal(bool) # Emits True for connected, False for disconnected/error
    # sequence_upload_status signal is removed as status is handled by MainWindow based on ACKs

    def __init__(self, port, baudrate=115200):
        super().__init__()
        self.port = port
        self.baudrate = baudrate
        self.serial_connection = None
        self.running = True          # Flag to control the run loop
        print(f"SerialWorker initialized for port {self.port} @ {self.baudrate} baud.")

    def run(self):
        """The main loop for the serial worker thread."""
        print(f"SerialWorker thread starting for {self.port}...")
        try:
            # Attempt to establish serial connection
            self.serial_connection = serial.Serial(self.port, self.baudrate, timeout=1)
            print(f"Serial port {self.port} opened successfully.")
            self.connection_status.emit(True)  # Signal successful connection

            # Main reading loop
            while self.running:
                if self.serial_connection is None or not self.serial_connection.is_open:
                     print("Serial connection lost unexpectedly in run loop.")
                     self.connection_status.emit(False)
                     break # Exit loop if connection is lost

                # Check if data is available to read
                if self.serial_connection.in_waiting > 0:
                    try:
                        # Read a line, decode, and strip whitespace
                        line = self.serial_connection.readline().decode('utf-8', errors='ignore').rstrip()
                        if line: # Only emit non-empty lines
                           self.data_received.emit(line)
                    except UnicodeDecodeError:
                         print("Warning: SerialWorker encountered UnicodeDecodeError. Ignoring byte.")
                    except serial.SerialException as read_error:
                         print(f"Serial read error in run loop: {read_error}")
                         self.connection_status.emit(False)
                         break # Exit loop on read error
                else:
                    # Small sleep to prevent high CPU usage when idle
                    time.sleep(0.02) # 20ms sleep

        except serial.SerialException as e:
            # Handle errors during initial connection attempt
            print(f"Serial connection error on port {self.port}: {e}")
            self.connection_status.emit(False)
        except Exception as e:
            # Handle unexpected errors in the thread
            print(f"An unexpected error occurred in SerialWorker run loop: {e}")
            self.connection_status.emit(False)
        finally:
            # Cleanup: Ensure the serial port is closed when the thread stops
            if self.serial_connection and self.serial_connection.is_open:
                self.serial_connection.close()
                print(f"Serial port {self.port} closed.")
            # Signal final disconnection status
            self.connection_status.emit(False)
            print(f"SerialWorker thread for {self.port} finished.")

    def stop(self):
        """Signals the worker thread to stop."""
        print(f"Stopping SerialWorker thread for {self.port}...")
        self.running = False
        self.wait(2000) # Wait up to 2 seconds for the thread to finish gracefully

    def send_data(self, data):
        """
        Thread-safe method to send data to the ESP32.
        Encodes to UTF-8. The CALLER is responsible for adding newlines.
        Returns True on successful write attempt, False otherwise.
        """
        try:
            if not self.isRunning() or not self.serial_connection:
                print("Serial worker not running or connection invalid. Cannot send.")
                return False

            if not self.serial_connection.is_open:
                print("Serial connection closed unexpectedly. Cannot send.")
                self.connection_status.emit(False)
                return False

            # *** CHANGE IS HERE: We no longer add a newline automatically. ***
            # The calling function must now provide it.
            data_to_send = data

            # Perform the write operation
            self.serial_connection.write(data_to_send.encode('utf-8'))
            self.serial_connection.flush()
            # print(f"Sent RAW: {data_to_send}") # Optional: Debug print for sent data
            return True

        except serial.SerialTimeoutException:
            print(f"Error sending data: Serial Timeout on port {self.port}")
            self.connection_status.emit(False)
            return False
        except serial.SerialException as e:
            print(f"Error sending data: Serial Exception on port {self.port}: {e}")
            self.connection_status.emit(False)
            return False
        except Exception as e:
            print(f"Error sending data: Unexpected error: {e}")
            return False

# END SECTION 2: SerialWorker Class


# END SECTION 2: SerialWorker Class


# START SECTION 2.5: WiFiWorker Class
import socket
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
